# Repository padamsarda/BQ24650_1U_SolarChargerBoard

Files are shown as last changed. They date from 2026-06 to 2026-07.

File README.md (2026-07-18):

# BQ24650 1U SolarChargerBoard 

A dev/eval board for the **TI BQ24650** standalone solar battery charger IC. The board was developed to provide a simpler and more custom platform for evaluating the BQ24650 for ANANTSAT-I(1u mission) after the standard eval-board proved unsuitable for the intended testing. It implements the complete synchronous buck battery charger power stage required by the charger IC, while exposing adjustable potentiometers for configuring the battery regulation voltage and the constant-voltage MPPT operating point, also has LEDs for the BQ2460 status pins. Temp sense pin is available for using external thermocoupler/thermistor.

### Board at a glance

| Item | Description |
| --- | --- |
| Charger IC | Texas Instruments BQ24650 |
| MPPT | Adjustable constant-voltage MPPT using potentiometer |
| Input Source | Solar panel |
| Charge Voltage | Adjustable using potentiometer |
| Power Stage | External NMOS MOSFETs and inductor |
| Monitoring | Multiple test points for evaluation |
| Temperature Input | TS connector for battery temperature sensing |

## Schematic

Schematic

## PCB

<p align="center">
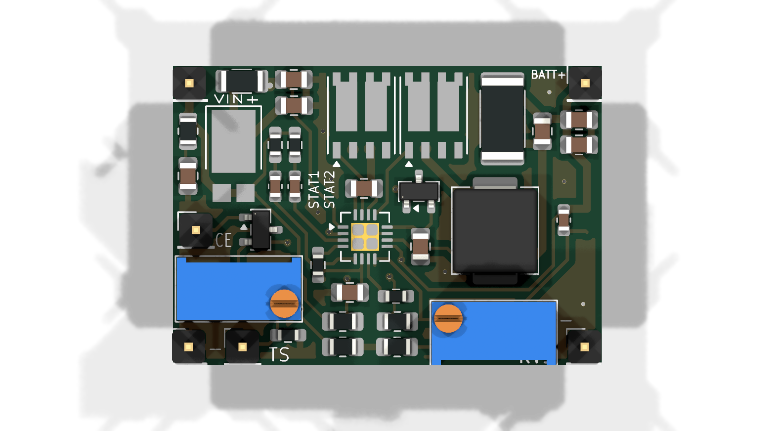
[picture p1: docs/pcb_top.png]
PCB Top
  
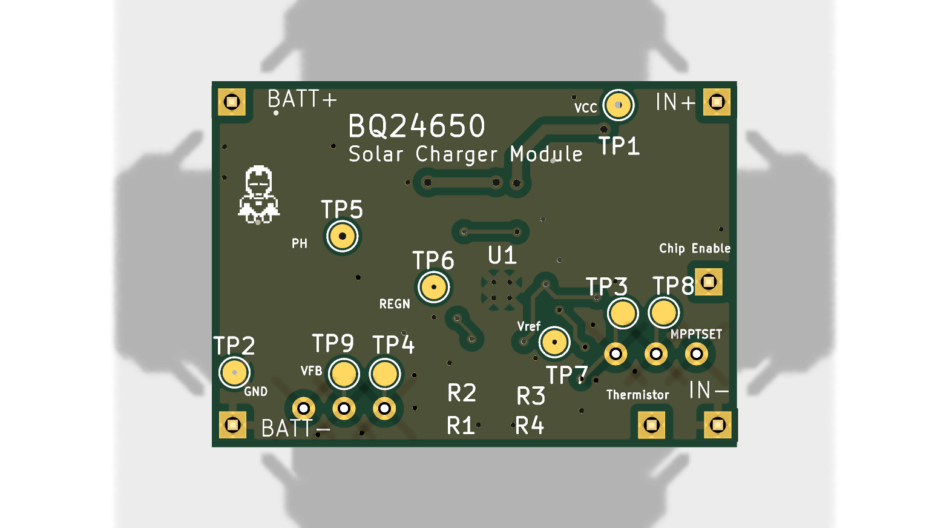
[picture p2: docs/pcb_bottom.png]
PCB Bottom
  
</p>

## Key Components

| Reference  | Part | Function |
| --- | --- | --- |
| U1 | BQ24650 | Solar battery charger controller |
| Q1, Q2, Q3 | NMOS MOSFET | Synchronous buck power stage, act as switch for shut down |
| L1 | Inductor | Buck converter |
| D2 | Schottky Diode | Power path/freewheeling diode |
| RV1 | Potentiometer  | Battery regulation voltage adjustment |
| RV2 | Potentiometer  | MPPT voltage adjustment |
| D1 | Power diode | Input protection / power path |

## Connectors & I/O

| Reference | Interface | Description |
| --- | --- | --- |
| J1 | CE/MPPSET | Charger enable and MPPT configuration |
| J2 | Solar+ | Solar panel input |
| J3 | Solar− | Solar panel return |
| J4 | BATT+ | Battery positive connection |
| J5 | BATT− | Battery return |
| J6 | TS | Battery temperature sensing input |
| TP1–TP9 | Test Points | Circuit measurement and debugging |

Designed and developed as part of **Team Anant**.

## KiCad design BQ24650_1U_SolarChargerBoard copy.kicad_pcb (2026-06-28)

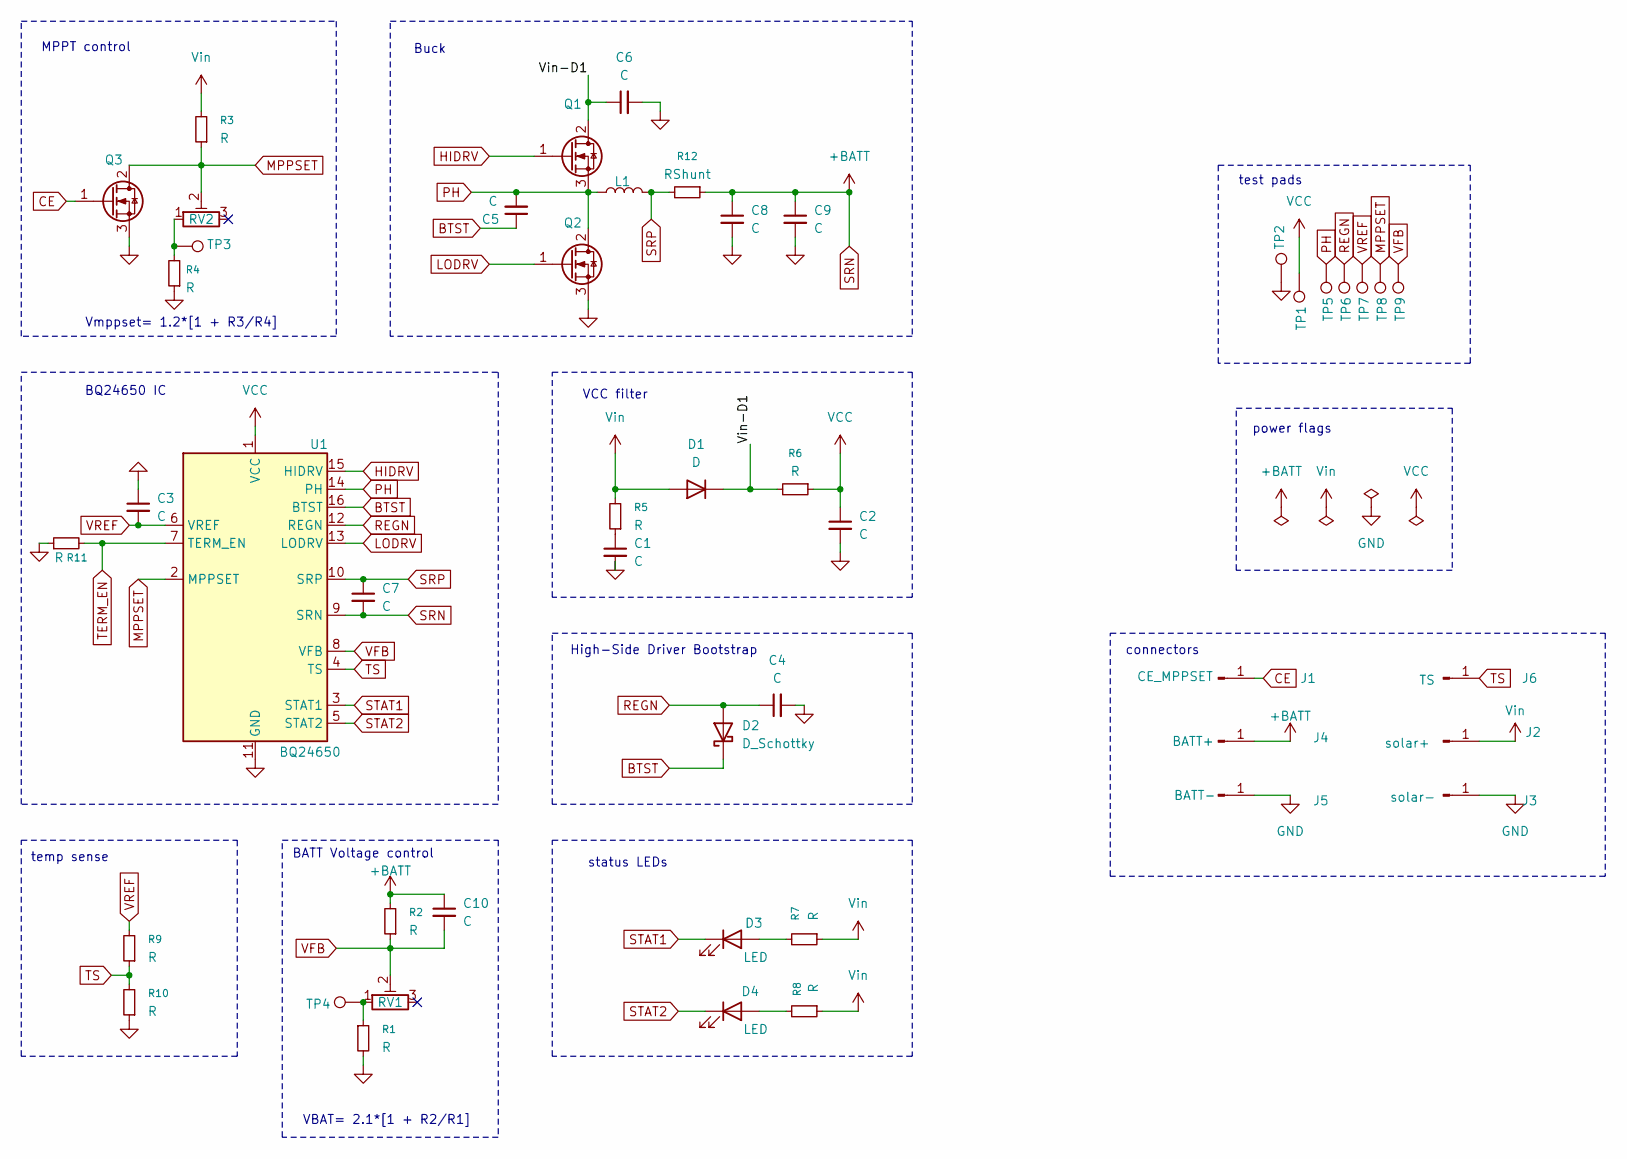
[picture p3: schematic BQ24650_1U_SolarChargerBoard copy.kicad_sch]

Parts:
C1, C2, C3, C4, C5, C6, C7, C8, C9: C; C_0805_2012Metric
C10: C; C_0603_1608Metric
D1: D; D_PowerDI-5
D2: D_Schottky; SOT-23
D3, D4: LED; C_0603_1608Metric
J1: CE_MPPSET; PinHeader_1x01_P2.54mm_Vertical
J2: solar+; PinHeader_1x01_P2.54mm_Vertical
J3: solar-; PinHeader_1x01_P2.54mm_Vertical
J4: BATT+; PinHeader_1x01_P2.54mm_Vertical
J5: BATT-; PinHeader_1x01_P2.54mm_Vertical
J6: TS; PinHeader_1x01_P2.54mm_Vertical
L1: L; L_Vishay_IHLP-2525
Q1, Q2: Q_NMOS_GDS; PowerPAK_SO-8_Dual
Q3: Q_NMOS_GDS; SOT-23
R1, R2, R3, R4: R; R_0805_2012Metric_Pad1.20x1.40mm_HandSolder
R5: R; R_0805_2012Metric
R6: R; R_1206_3216Metric
R7, R8, R9, R10, R11: R; R_0603_1608Metric_Pad0.98x0.95mm_HandSolder
R12: RShunt; R_2512_6332Metric
RV1, RV2: R_Potentiometer_Trim; Potentiometer_Bourns_3296W_Vertical
TP1, TP2, TP3, TP4, TP5, TP6, TP7, TP8, TP9: TestPoint; TestPoint_Pad_D1.5mm
U1: BQ24650; Texas_RVA_VQFN-16-1EP_3.5x3.5mm_P0.5mm_EP2.14x2.14mm_Therma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

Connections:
/Vin-D1: C6.1, D1.1 (K), Q1.2 (D), R6.2
BTST: C5.1, D2.1 (K), U1.16 (BTST)
CE: J1.1 (Pin_1_1), Q3.1 (G)
GND: C1.2, C2.2, C3.1, C4.2, C6.2, C8.2, C9.2, J3.1 (Pin_1_1), J5.1 (Pin_1_1), Q2.3 (S), Q3.3 (S), R1.2, R4.1, R10.1, R11.1, TP2.1 (1_1), U1.11 (GND), U1.17 (GND)
HIDRV: Q1.1 (G), U1.15 (HIDRV)
LODRV: Q2.1 (G), U1.13 (LODRV)
MPPSET: Q3.2 (D), R3.1, RV2.2, TP8.1 (1_1), U1.2 (MPPSET)
unnamed: C1.1, R5.1
unnamed: D3.2 (A), R7.2
unnamed: D4.2 (A), R8.2
unnamed: R1.1, RV1.1, TP4.1 (1_1)
unnamed: R4.2, RV2.1, TP3.1 (1_1)
PH: C5.2, L1.1, Q1.3 (S), Q2.2 (D), TP5.1 (1_1), U1.14 (PH)
REGN: C4.1, D2.2 (A), TP6.1 (1_1), U1.12 (REGN)
SRN: C7.2, C8.1, C9.1, C10.1, J4.1 (Pin_1_1), R2.2, R12.1, U1.9 (SRN)
SRP: C7.1, L1.2, R12.2, U1.10 (SRP)
STAT1: D3.1 (K), U1.3 (STAT1)
STAT2: D4.1 (K), U1.5 (STAT2)
TERM_EN: R11.2, U1.7 (TERM_EN)
TS: J6.1 (Pin_1_1), R9.1, R10.2, U1.4 (TS)
VCC: C2.1, R6.1, TP1.1 (1_1), U1.1 (VCC)
VFB: C10.2, R2.1, RV1.2, TP9.1 (1_1), U1.8 (VFB)
VREF: C3.2, R9.2, TP7.1 (1_1), U1.6 (VREF)
Vin: D1.2 (A), J2.1 (Pin_1_1), R3.2, R5.2, R7.1, R8.1

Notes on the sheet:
VBAT= 2.1*[1 + R2/R1]
BATT Voltage control
status LEDs
power flags
Buck
Vmppset= 1.2*[1 + R3/R4]
High-Side Driver Bootstrap
connectors
VCC filter
MPPT control
BQ24650 IC
temp sense
test pads

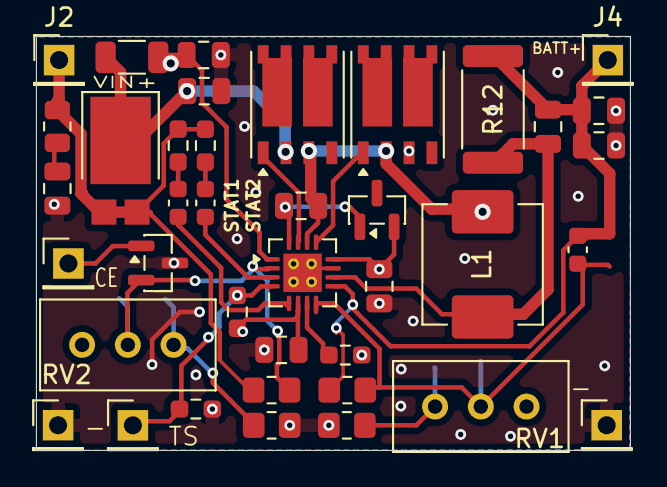
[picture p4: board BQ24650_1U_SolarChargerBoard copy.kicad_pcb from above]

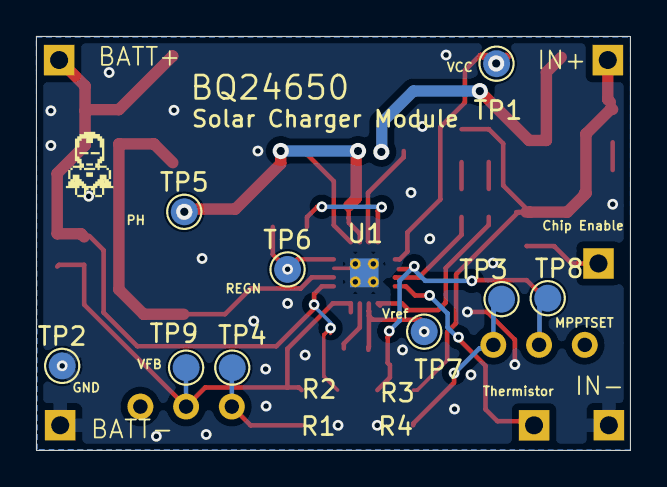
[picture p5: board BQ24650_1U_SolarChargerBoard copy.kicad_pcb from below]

Board: 2 copper layers, 33.0 x 23.0 mm, 48 parts (9 on the bottom side), 24 nets.

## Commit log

2026-06-23 Initial BQ24650 evaluation board schematic
    [BQ24650_eval.kicad_pcb, BQ24650_eval.kicad_sch]
2026-06-23 Add .gitignore and remove generated KiCad files
2026-06-24 small changes
    [BQ24650_1U_SolarChargerBoard.kicad_pcb, BQ24650_1U_SolarChargerBoard.kicad_sch]
2026-06-24 Assigned footprints
    [BQ24650_1U_SolarChargerBoard copy.kicad_pcb, BQ24650_1U_SolarChargerBoard copy.kicad_sch, BQ24650_1U_SolarChargerBoard.kicad_pcb]
2026-06-25 decided Front and back components
    [BQ24650_1U_SolarChargerBoard copy.kicad_pcb, BQ24650_1U_SolarChargerBoard copy.kicad_sch]
2026-06-27 finishing touches
    [BQ24650_1U_SolarChargerBoard copy.kicad_pcb]
